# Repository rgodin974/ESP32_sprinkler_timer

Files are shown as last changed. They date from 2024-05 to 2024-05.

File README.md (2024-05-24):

# ESP32_sprinkler_timer

Sprinkler timer designed for ESP32.

Coded on PlateformIO and VS Code. Project based on RitonDuino : https://riton-duino.blogspot.com/2023/08/esp32-micro-irrigation-connectee-partie.html

Add few features :
- waterings every days
- waterings even days
- waterings odd days
- waterings custom days
- seasonal adjustment
- enable/disable watering(s)

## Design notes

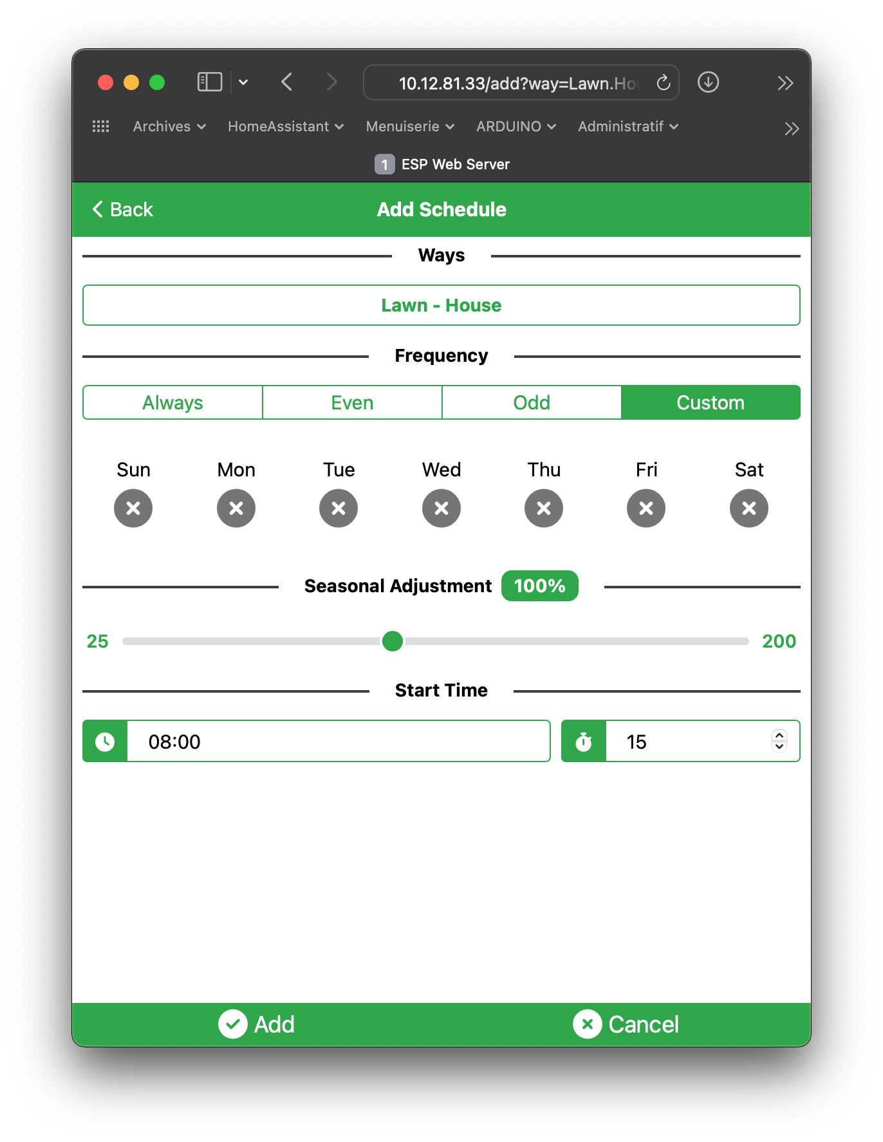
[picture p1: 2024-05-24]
sprinkler_add.png

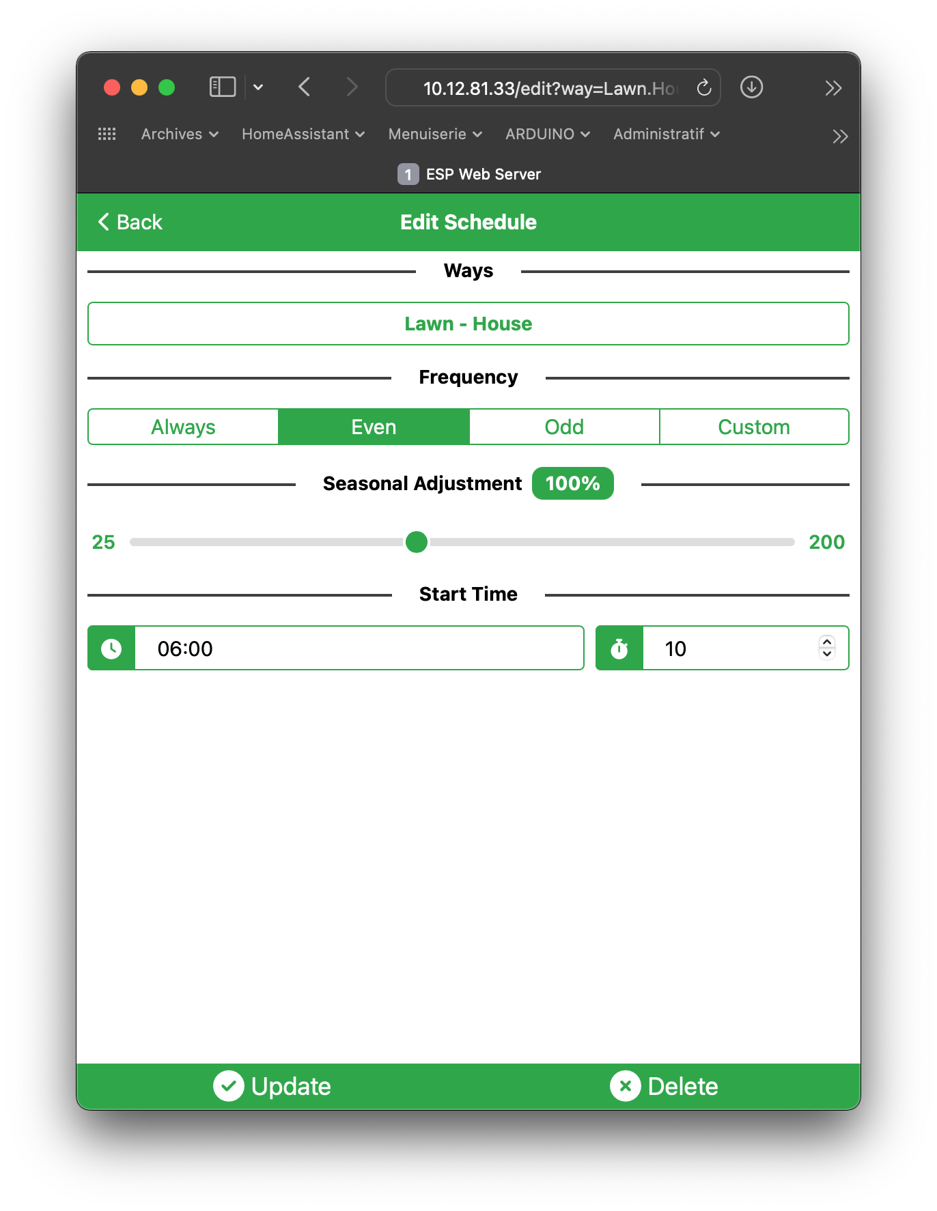
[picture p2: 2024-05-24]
sprinkler_edit.png

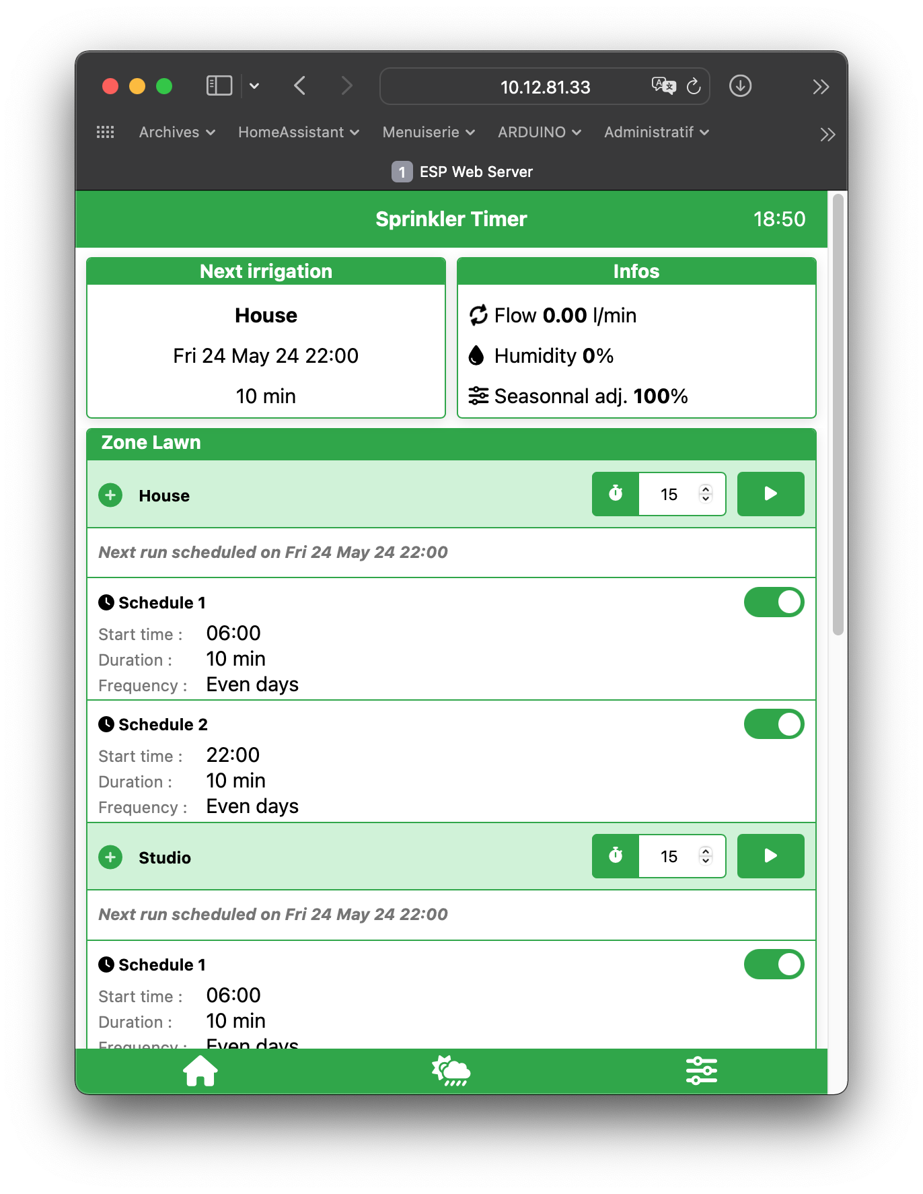
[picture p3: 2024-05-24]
sprinkler_home.png

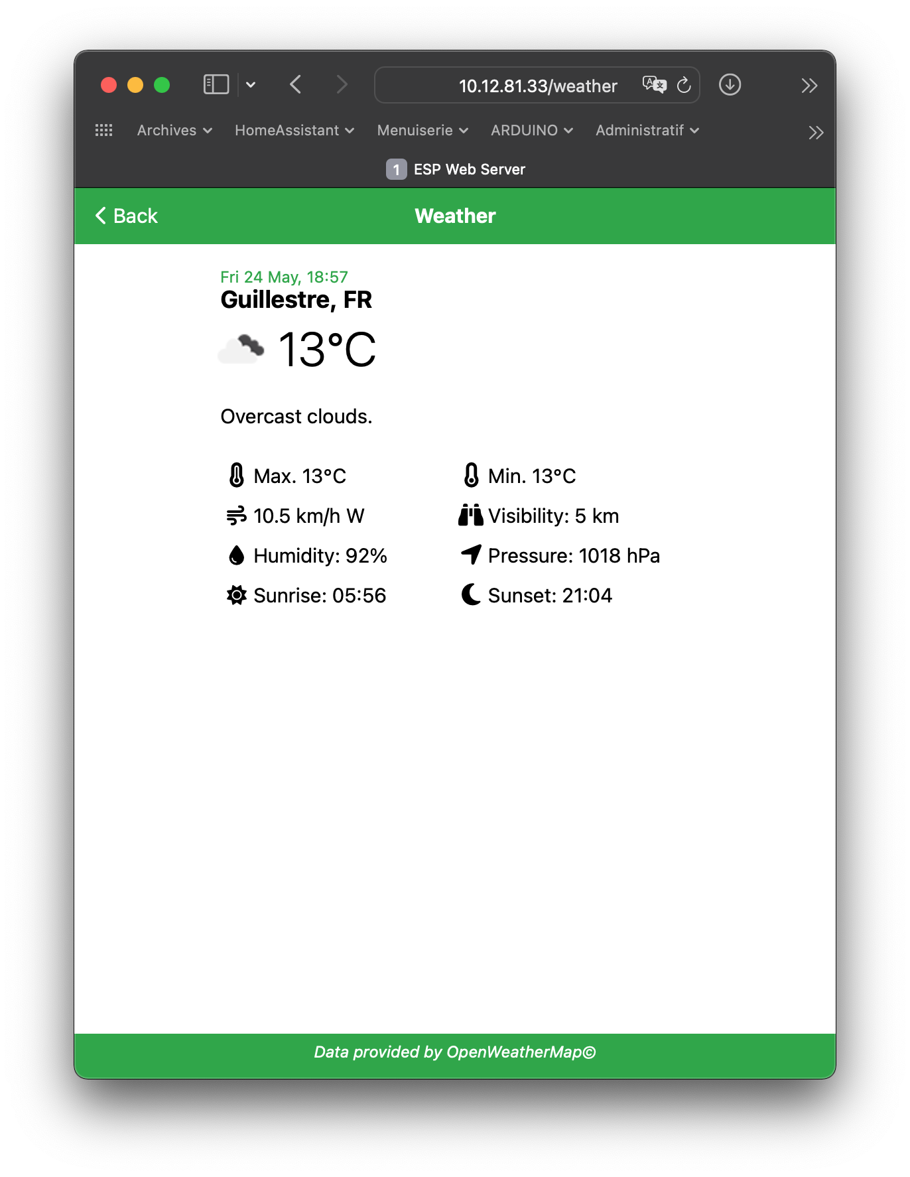
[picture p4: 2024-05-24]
sprinkler_weather.png

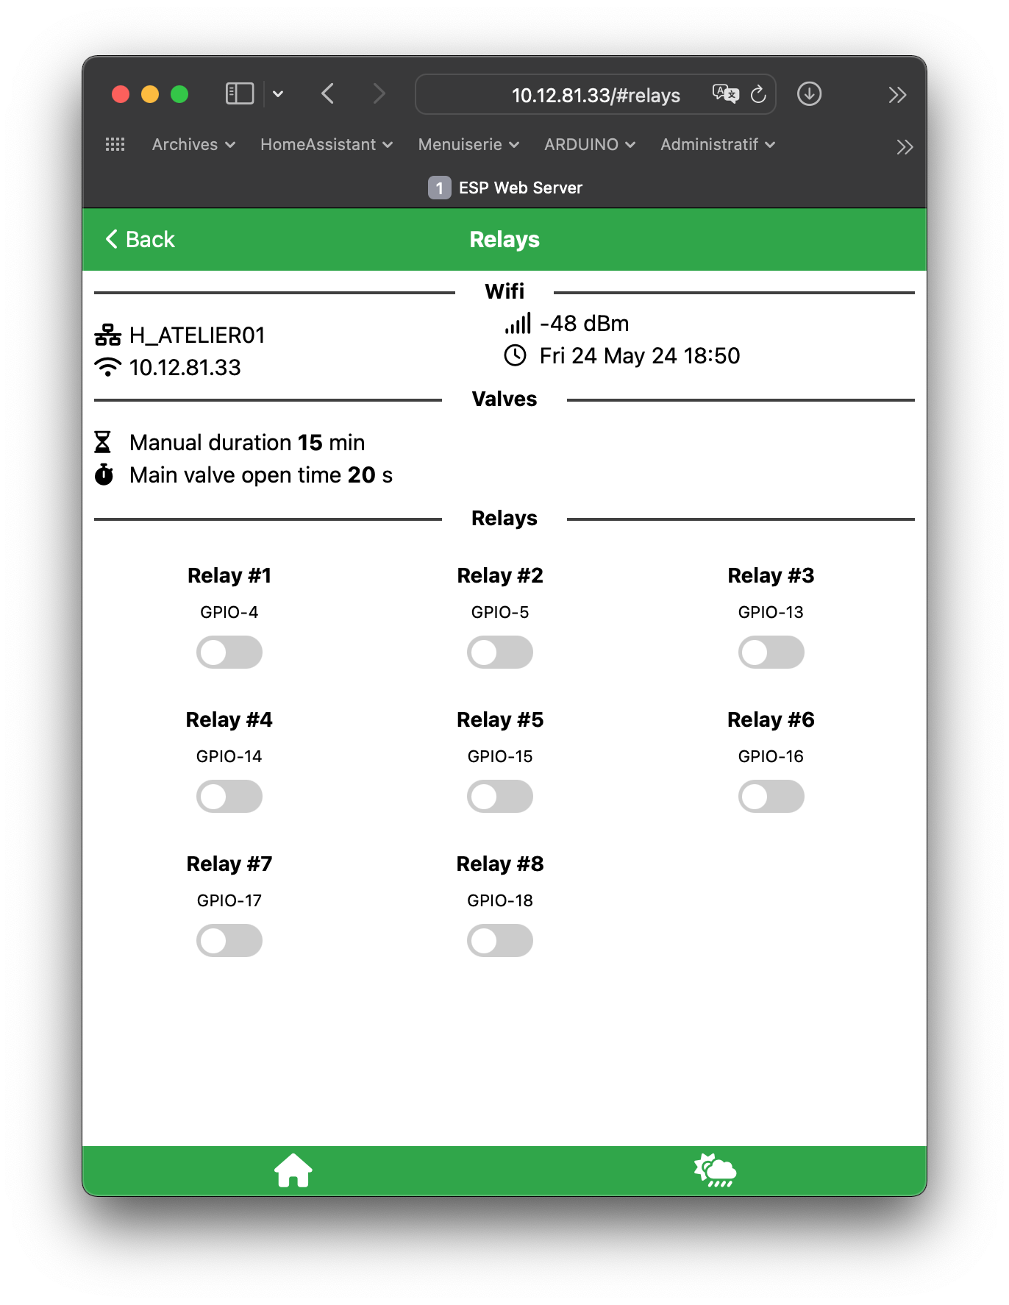
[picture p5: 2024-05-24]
sprinkler_infos.png

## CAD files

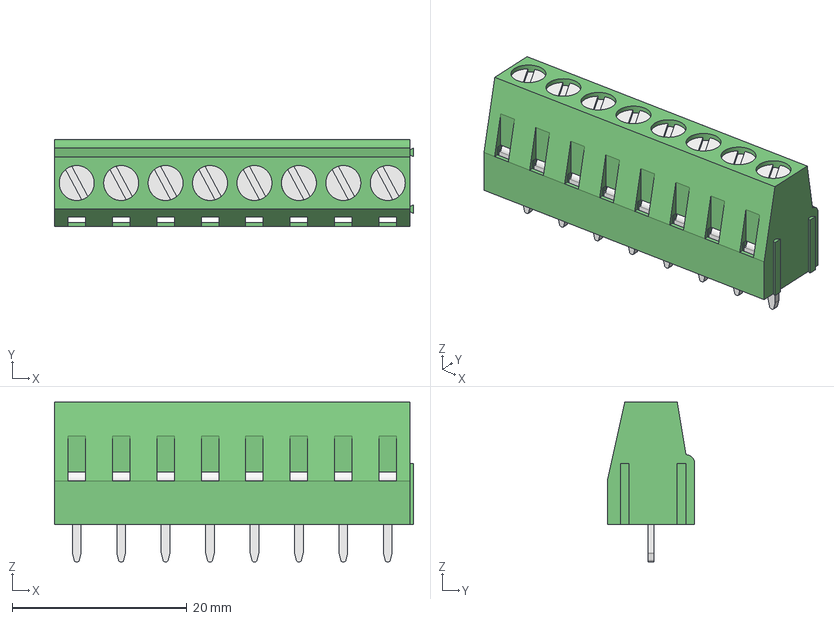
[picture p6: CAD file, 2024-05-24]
KiCAD/3D/8er Terminal Block.step
41.0 x 10.0 x 18.2 mm
Pin (1) (16)
Tornillo (1) (16)
Cubo interno (1) (16)
Pin (1) (1) (15)
Tornillo (1) (1) (15)
Cubo interno (1) (1) (15)
Pin (1) (14) (1)
Tornillo (1) (14) (1)
Cubo interno (1) (14) (1)
Pin (1) (1) (13) (1)
Tornillo (1) (1) (13) (1)
Cubo interno (1) (1) (13) (1)
Pin (1) (19) (1) (1) (1) (1) (1) (1)
Tornillo (1) (19) (1) (1) (1) (1) (1) (1)
Cubo interno (1) (19) (1) (1) (1) (1) (1) (1)
Pin (1) (1) (18) (1) (1) (1) (1) (1) (1)
Tornillo (1) (1) (18) (1) (1) (1) (1) (1) (1)
Cubo interno (1) (1) (18) (1) (1) (1) (1) (1) (1)
Pin (1) (11) (1) (1) (1) (1) (1) (1)
Tornillo (1) (11) (1) (1) (1) (1) (1) (1)
Cubo interno (1) (11) (1) (1) (1) (1) (1) (1)
Pin (1) (1) (10) (1) (1) (1) (1) (1) (1)
Tornillo (1) (1) (10) (1) (1) (1) (1) (1) (1)
Cubo interno (1) (1) (10) (1) (1) (1) (1) (1) (1)
Pin (1) (17) (1) (1) (1) (1) (1)
Tornillo (1) (17) (1) (1) (1) (1) (1)
Cubo interno (1) (17) (1) (1) (1) (1) (1)
Pin (1) (1) (16) (1) (1) (1) (1) (1)
Tornillo (1) (1) (16) (1) (1) (1) (1) (1)
Cubo interno (1) (1) (16) (1) (1) (1) (1) (1)
Pin (1) (18) (1) (1) (1) (1)
Tornillo (1) (18) (1) (1) (1) (1)
Cubo interno (1) (18) (1) (1) (1) (1)
Pin (1) (1) (17) (1) (1) (1) (1)
Tornillo (1) (1) (17) (1) (1) (1) (1)
Cubo interno (1) (1) (17) (1) (1) (1) (1)
Pin (1) (20) (1) (1) (1)
Tornillo (1) (20) (1) (1) (1)
Cubo interno (1) (20) (1) (1) (1)
Pin (1) (1) (19) (1) (1) (1)
Tornillo (1) (1) (19) (1) (1) (1)
Cubo interno (1) (1) (19) (1) (1) (1)
Pin (1) (13) (1) (1)
Tornillo (1) (13) (1) (1)
Cubo interno (1) (13) (1) (1)
Pin (1) (1) (12) (1) (1)
Tornillo (1) (1) (12) (1) (1)
Cubo interno (1) (1) (12) (1) (1)

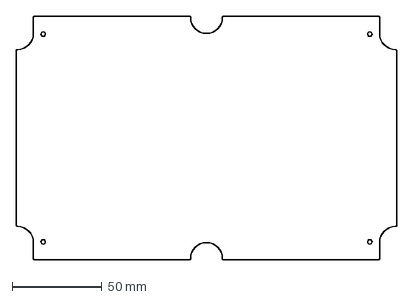
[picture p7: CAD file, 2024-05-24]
KiCAD/Board.dxf
211.3 x 135.3 mm

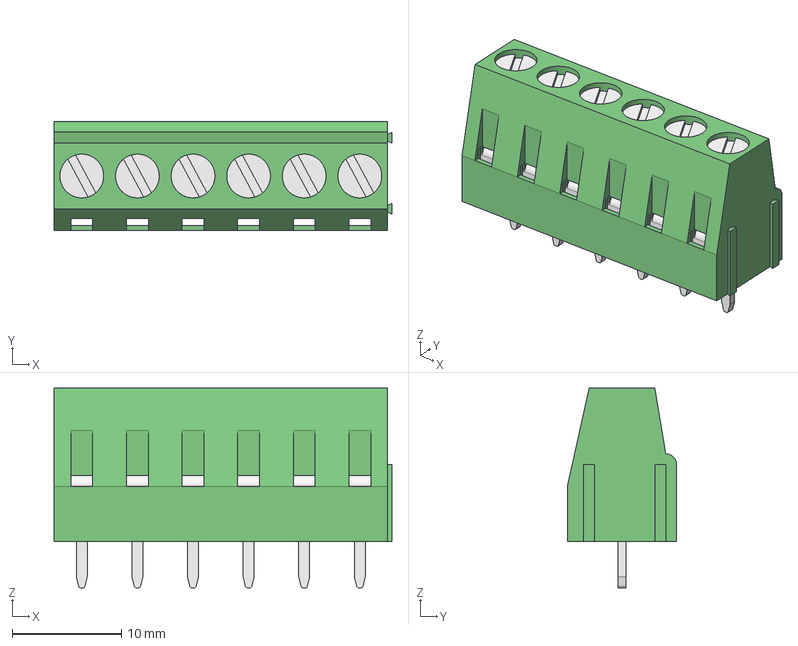
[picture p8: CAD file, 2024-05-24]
KiCAD/3D/6er Terminal Block.step
30.9 x 10.0 x 18.2 mm
Pin (1) (19) (1) (1) (1) (1)
Tornillo (1) (19) (1) (1) (1) (1)
Cubo interno (1) (19) (1) (1) (1) (1)
Pin (1) (1) (18) (1) (1) (1) (1)
Tornillo (1) (1) (18) (1) (1) (1) (1)
Cubo interno (1) (1) (18) (1) (1) (1) (1)
Pin (1) (11) (1) (1) (1) (1)
Tornillo (1) (11) (1) (1) (1) (1)
Cubo interno (1) (11) (1) (1) (1) (1)
Pin (1) (1) (10) (1) (1) (1) (1)
Tornillo (1) (1) (10) (1) (1) (1) (1)
Cubo interno (1) (1) (10) (1) (1) (1) (1)
Pin (1) (17) (1) (1) (1)
Tornillo (1) (17) (1) (1) (1)
Cubo interno (1) (17) (1) (1) (1)
Pin (1) (1) (16) (1) (1) (1)
Tornillo (1) (1) (16) (1) (1) (1)
Cubo interno (1) (1) (16) (1) (1) (1)
Pin (1) (18) (1) (1)
Tornillo (1) (18) (1) (1)
Cubo interno (1) (18) (1) (1)
Pin (1) (1) (17) (1) (1)
Tornillo (1) (1) (17) (1) (1)
Cubo interno (1) (1) (17) (1) (1)
Pin (1) (20) (1)
Tornillo (1) (20) (1)
Cubo interno (1) (20) (1)
Pin (1) (1) (19) (1)
Tornillo (1) (1) (19) (1)
Cubo interno (1) (1) (19) (1)
Pin (1) (13)
Tornillo (1) (13)
Cubo interno (1) (13)
Pin (1) (1) (12)
Tornillo (1) (1) (12)
Cubo interno (1) (1) (12)

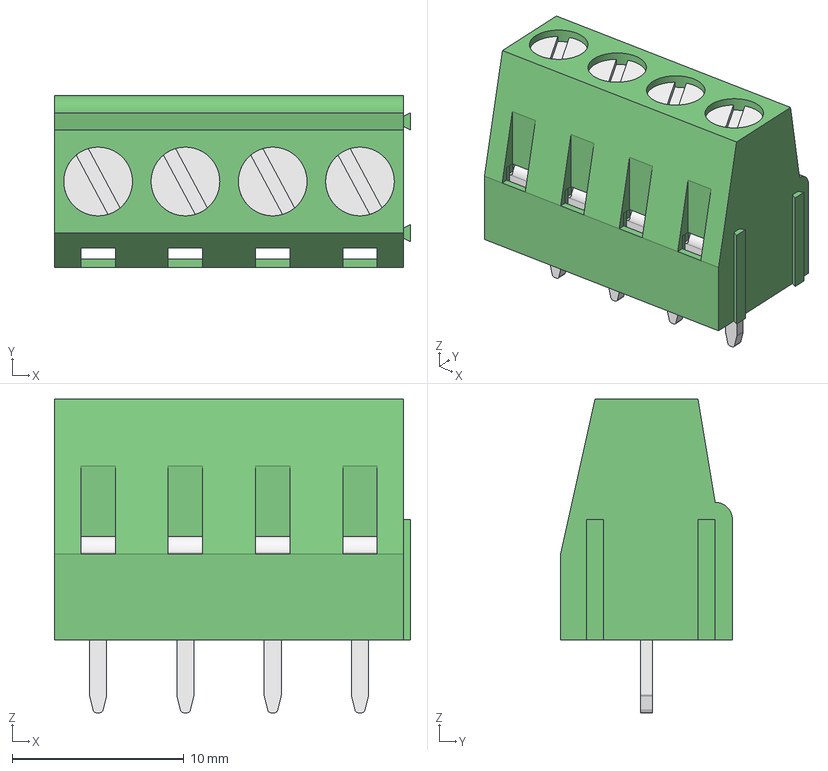
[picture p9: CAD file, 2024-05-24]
KiCAD/3D/4er Terminal Block.step
20.7 x 10.0 x 18.2 mm
Pin (1) (19) (1) (1)
Tornillo (1) (19) (1) (1)
Cubo interno (1) (19) (1) (1)
Pin (1) (1) (18) (1) (1)
Tornillo (1) (1) (18) (1) (1)
Cubo interno (1) (1) (18) (1) (1)
Pin (1) (11) (1) (1)
Tornillo (1) (11) (1) (1)
Cubo interno (1) (11) (1) (1)
Pin (1) (1) (10) (1) (1)
Tornillo (1) (1) (10) (1) (1)
Cubo interno (1) (1) (10) (1) (1)
Pin (1) (17) (1)
Tornillo (1) (17) (1)
Cubo interno (1) (17) (1)
Pin (1) (1) (16) (1)
Tornillo (1) (1) (16) (1)
Cubo interno (1) (1) (16) (1)
Pin (1) (18)
Tornillo (1) (18)
Cubo interno (1) (18)
Pin (1) (1) (17)
Tornillo (1) (1) (17)
Cubo interno (1) (1) (17)

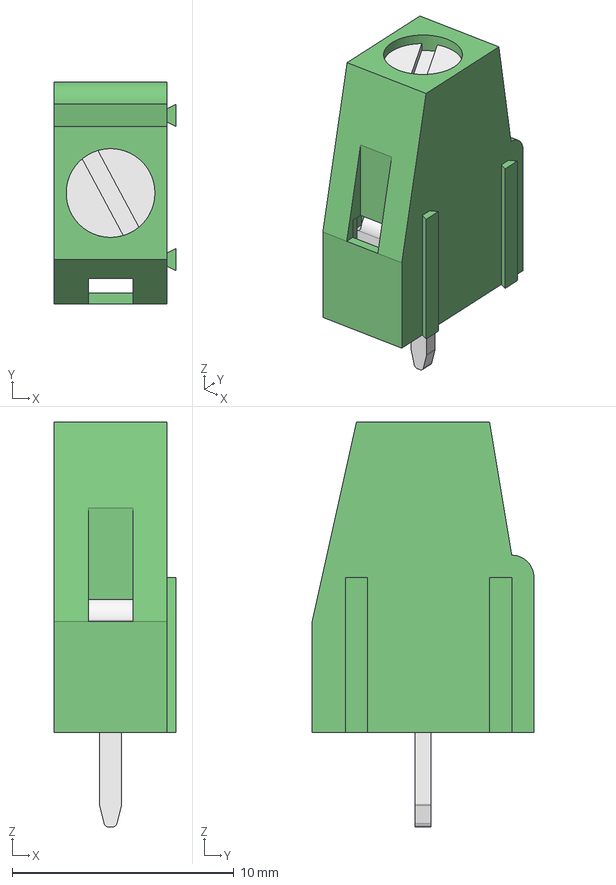
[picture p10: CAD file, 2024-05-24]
KiCAD/3D/1er Terminal Block.step
5.48 x 10.0 x 18.2 mm
Pin (1)
Tornillo (1)
Cubo interno (1)
Pin (1) (1)
Tornillo (1) (1)
Cubo interno (1) (1)

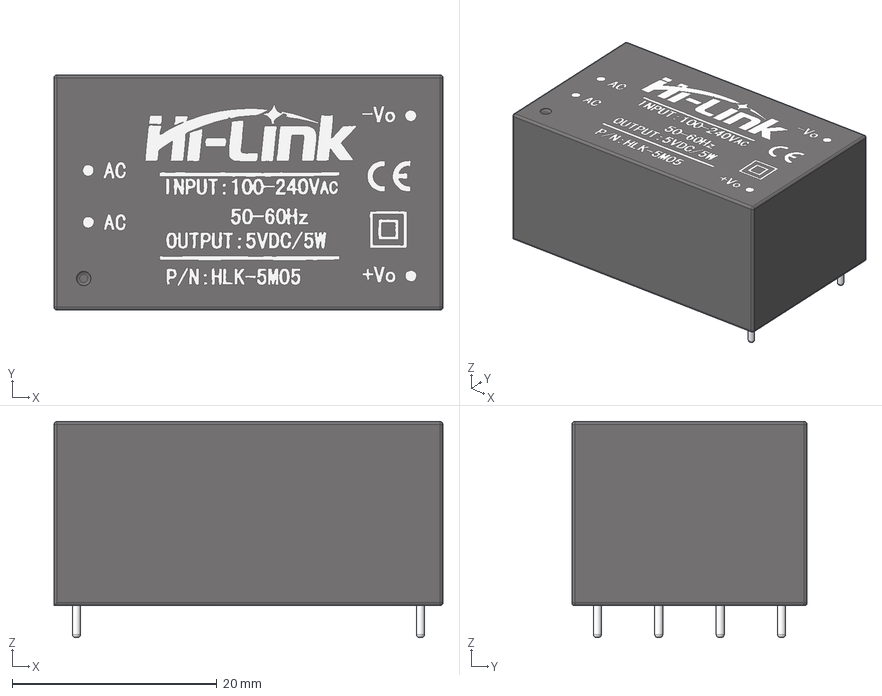
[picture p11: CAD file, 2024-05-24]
KiCAD/3D/HLK-5M05.step
38.0 x 23.0 x 21.1 mm

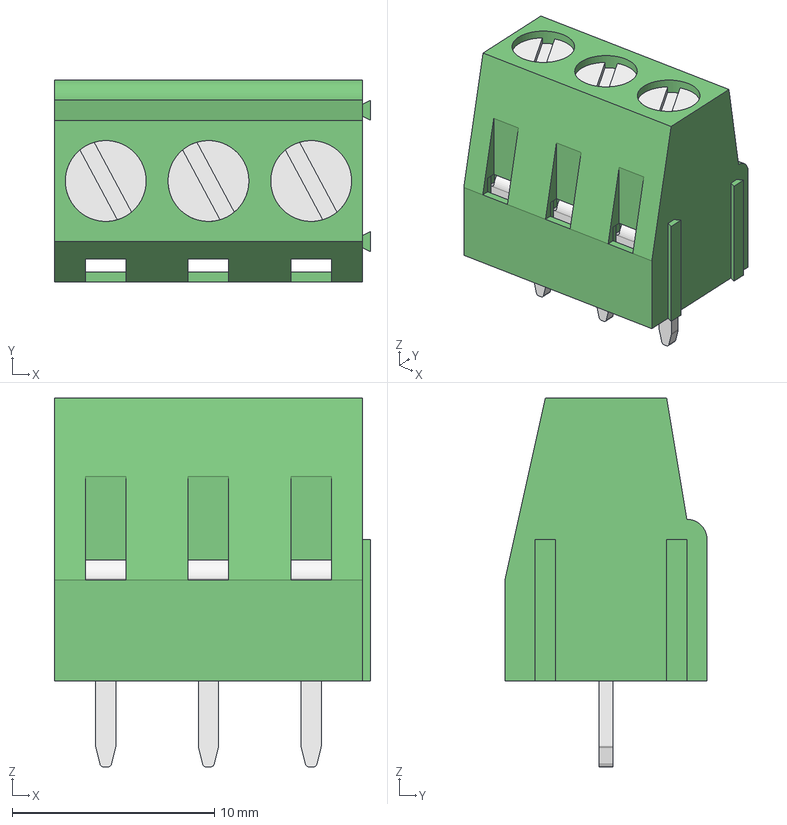
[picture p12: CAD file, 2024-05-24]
KiCAD/3D/3er Terminal Block.step
15.6 x 10.0 x 18.2 mm
Pin (1) (19) (1)
Tornillo (1) (19) (1)
Cubo interno (1) (19) (1)
Pin (1) (1) (18) (1)
Tornillo (1) (1) (18) (1)
Cubo interno (1) (1) (18) (1)
Pin (1) (11) (1)
Tornillo (1) (11) (1)
Cubo interno (1) (11) (1)
Pin (1) (1) (10) (1)
Tornillo (1) (1) (10) (1)
Cubo interno (1) (1) (10) (1)
Pin (1) (17)
Tornillo (1) (17)
Cubo interno (1) (17)
Pin (1) (1) (16)
Tornillo (1) (1) (16)
Cubo interno (1) (1) (16)

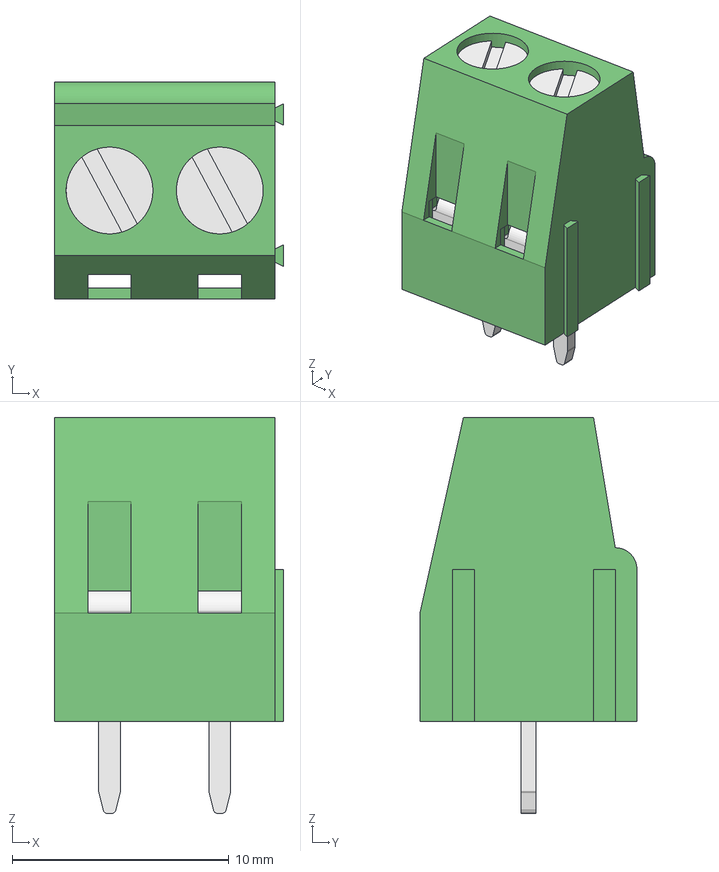
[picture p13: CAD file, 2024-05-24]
KiCAD/3D/2er Terminal Block.step
10.6 x 10.0 x 18.2 mm
Pin (1) (19)
Tornillo (1) (19)
Cubo interno (1) (19)
Pin (1) (1) (18)
Tornillo (1) (1) (18)
Cubo interno (1) (1) (18)
Pin (1) (11)
Tornillo (1) (11)
Cubo interno (1) (11)
Pin (1) (1) (10)
Tornillo (1) (1) (10)
Cubo interno (1) (1) (10)

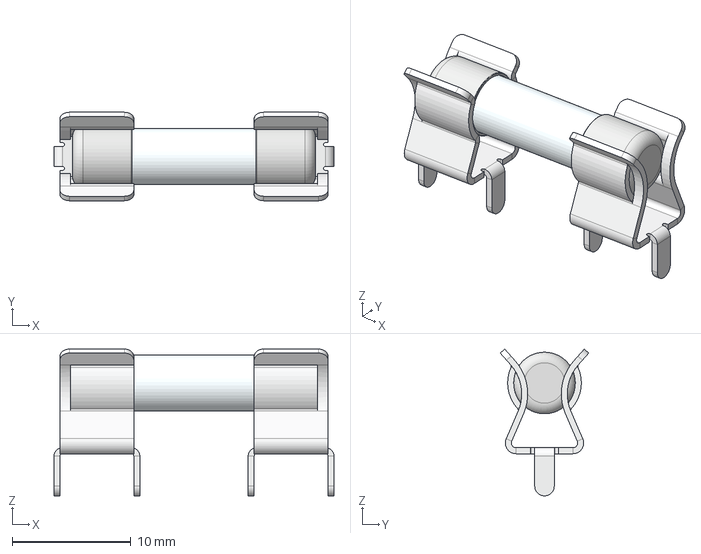
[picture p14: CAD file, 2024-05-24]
KiCAD/3D/FC-201-22_5TT.stp
23.6 x 7.47 x 12.4 mm

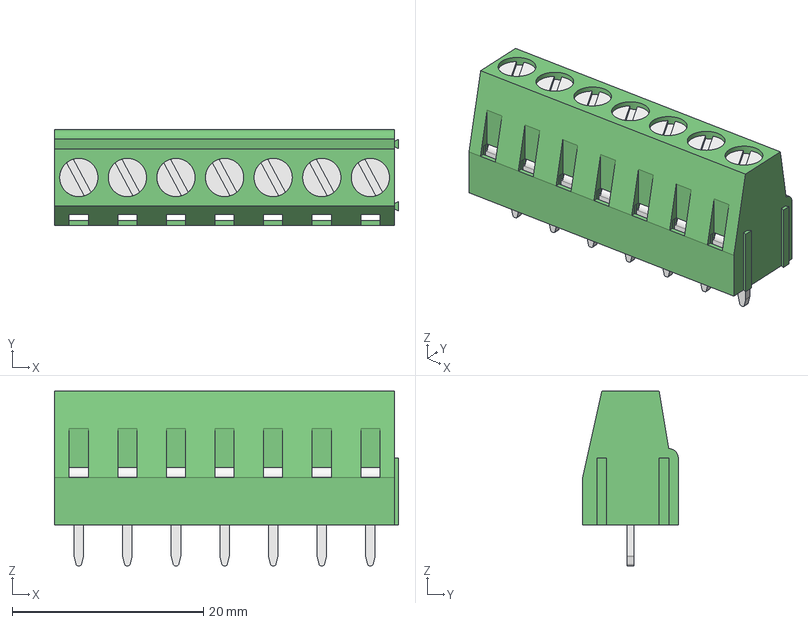
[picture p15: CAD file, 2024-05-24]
KiCAD/3D/7er Terminal Block.step
36.0 x 10.0 x 18.2 mm
Pin (1) (14)
Tornillo (1) (14)
Cubo interno (1) (14)
Pin (1) (1) (13)
Tornillo (1) (1) (13)
Cubo interno (1) (1) (13)
Pin (1) (19) (1) (1) (1) (1) (1)
Tornillo (1) (19) (1) (1) (1) (1) (1)
Cubo interno (1) (19) (1) (1) (1) (1) (1)
Pin (1) (1) (18) (1) (1) (1) (1) (1)
Tornillo (1) (1) (18) (1) (1) (1) (1) (1)
Cubo interno (1) (1) (18) (1) (1) (1) (1) (1)
Pin (1) (11) (1) (1) (1) (1) (1)
Tornillo (1) (11) (1) (1) (1) (1) (1)
Cubo interno (1) (11) (1) (1) (1) (1) (1)
Pin (1) (1) (10) (1) (1) (1) (1) (1)
Tornillo (1) (1) (10) (1) (1) (1) (1) (1)
Cubo interno (1) (1) (10) (1) (1) (1) (1) (1)
Pin (1) (17) (1) (1) (1) (1)
Tornillo (1) (17) (1) (1) (1) (1)
Cubo interno (1) (17) (1) (1) (1) (1)
Pin (1) (1) (16) (1) (1) (1) (1)
Tornillo (1) (1) (16) (1) (1) (1) (1)
Cubo interno (1) (1) (16) (1) (1) (1) (1)
Pin (1) (18) (1) (1) (1)
Tornillo (1) (18) (1) (1) (1)
Cubo interno (1) (18) (1) (1) (1)
Pin (1) (1) (17) (1) (1) (1)
Tornillo (1) (1) (17) (1) (1) (1)
Cubo interno (1) (1) (17) (1) (1) (1)
Pin (1) (20) (1) (1)
Tornillo (1) (20) (1) (1)
Cubo interno (1) (20) (1) (1)
Pin (1) (1) (19) (1) (1)
Tornillo (1) (1) (19) (1) (1)
Cubo interno (1) (1) (19) (1) (1)
Pin (1) (13) (1)
Tornillo (1) (13) (1)
Cubo interno (1) (13) (1)
Pin (1) (1) (12) (1)
Tornillo (1) (1) (12) (1)
Cubo interno (1) (1) (12) (1)

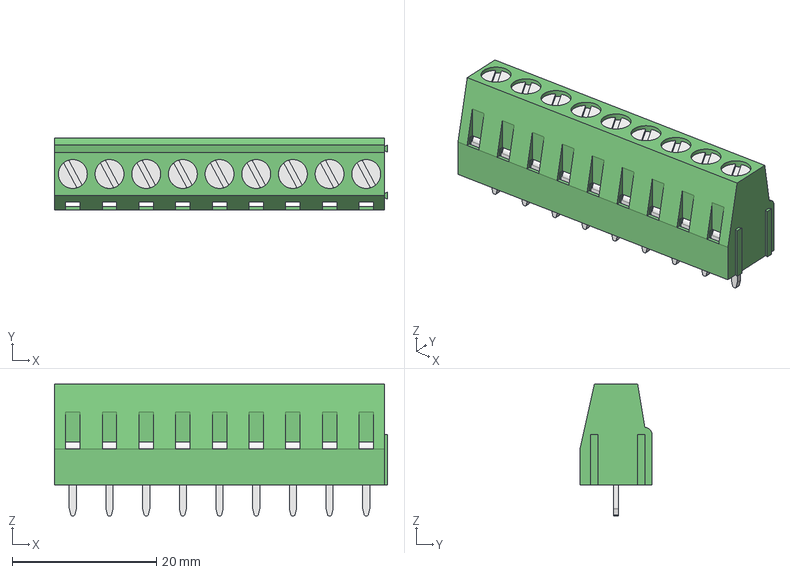
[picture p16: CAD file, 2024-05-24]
KiCAD/3D/9er Terminal Block.step
46.1 x 10.0 x 18.2 mm
Pin (1) (16) (1)
Tornillo (1) (16) (1)
Cubo interno (1) (16) (1)
Pin (1) (1) (15) (1)
Tornillo (1) (1) (15) (1)
Cubo interno (1) (1) (15) (1)
Pin (1) (14) (1) (1)
Tornillo (1) (14) (1) (1)
Cubo interno (1) (14) (1) (1)
Pin (1) (1) (13) (1) (1)
Tornillo (1) (1) (13) (1) (1)
Cubo interno (1) (1) (13) (1) (1)
Pin (1) (19) (1) (1) (1) (1) (1) (1) (1)
Tornillo (1) (19) (1) (1) (1) (1) (1) (1) (1)
Cubo interno (1) (19) (1) (1) (1) (1) (1) (1) (1)
Pin (1) (1) (18) (1) (1) (1) (1) (1) (1) (1)
Tornillo (1) (1) (18) (1) (1) (1) (1) (1) (1) (1)
Cubo interno (1) (1) (18) (1) (1) (1) (1) (1) (1) (1)
Pin (1) (11) (1) (1) (1) (1) (1) (1) (1)
Tornillo (1) (11) (1) (1) (1) (1) (1) (1) (1)
Cubo interno (1) (11) (1) (1) (1) (1) (1) (1) (1)
Pin (1) (1) (10) (1) (1) (1) (1) (1) (1) (1)
Tornillo (1) (1) (10) (1) (1) (1) (1) (1) (1) (1)
Cubo interno (1) (1) (10) (1) (1) (1) (1) (1) (1) (1)
Pin (1) (17) (1) (1) (1) (1) (1) (1)
Tornillo (1) (17) (1) (1) (1) (1) (1) (1)
Cubo interno (1) (17) (1) (1) (1) (1) (1) (1)
Pin (1) (1) (16) (1) (1) (1) (1) (1) (1)
Tornillo (1) (1) (16) (1) (1) (1) (1) (1) (1)
Cubo interno (1) (1) (16) (1) (1) (1) (1) (1) (1)
Pin (1) (18) (1) (1) (1) (1) (1)
Tornillo (1) (18) (1) (1) (1) (1) (1)
Cubo interno (1) (18) (1) (1) (1) (1) (1)
Pin (1) (1) (17) (1) (1) (1) (1) (1)
Tornillo (1) (1) (17) (1) (1) (1) (1) (1)
Cubo interno (1) (1) (17) (1) (1) (1) (1) (1)
Pin (1) (20) (1) (1) (1) (1)
Tornillo (1) (20) (1) (1) (1) (1)
Cubo interno (1) (20) (1) (1) (1) (1)
Pin (1) (1) (19) (1) (1) (1) (1)
Tornillo (1) (1) (19) (1) (1) (1) (1)
Cubo interno (1) (1) (19) (1) (1) (1) (1)
Pin (1) (13) (1) (1) (1)
Tornillo (1) (13) (1) (1) (1)
Cubo interno (1) (13) (1) (1) (1)
Pin (1) (1) (12) (1) (1) (1)
Tornillo (1) (1) (12) (1) (1) (1)
Cubo interno (1) (1) (12) (1) (1) (1)
Pin (1) (15)
Tornillo (1) (15)
Cubo interno (1) (15)
Pin (1) (1) (14)
Tornillo (1) (1) (14)
Cubo interno (1) (1) (14)

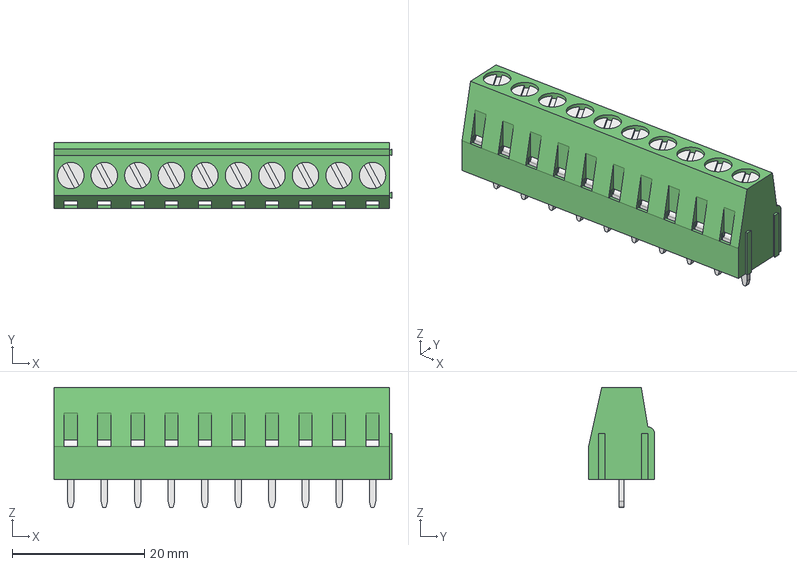
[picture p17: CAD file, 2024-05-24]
KiCAD/3D/10er Terminal Block.step
51.2 x 10.0 x 18.2 mm
Pin (1) (12)
Tornillo (1) (12)
Cubo interno (1) (12)
Pin (1) (1) (11)
Tornillo (1) (1) (11)
Cubo interno (1) (1) (11)
Pin (1) (16) (1) (1)
Tornillo (1) (16) (1) (1)
Cubo interno (1) (16) (1) (1)
Pin (1) (1) (15) (1) (1)
Tornillo (1) (1) (15) (1) (1)
Cubo interno (1) (1) (15) (1) (1)
Pin (1) (14) (1) (1) (1)
Tornillo (1) (14) (1) (1) (1)
Cubo interno (1) (14) (1) (1) (1)
Pin (1) (1) (13) (1) (1) (1)
Tornillo (1) (1) (13) (1) (1) (1)
Cubo interno (1) (1) (13) (1) (1) (1)
Pin (1) (19) (1) (1) (1) (1) (1) (1) (1) (1)
Tornillo (1) (19) (1) (1) (1) (1) (1) (1) (1) (1)
Cubo interno (1) (19) (1) (1) (1) (1) (1) (1) (1) (1)
Pin (1) (1) (18) (1) (1) (1) (1) (1) (1) (1) (1)
Tornillo (1) (1) (18) (1) (1) (1) (1) (1) (1) (1) (1)
Cubo interno (1) (1) (18) (1) (1) (1) (1) (1) (1) (1) (1)
Pin (1) (11) (1) (1) (1) (1) (1) (1) (1) (1)
Tornillo (1) (11) (1) (1) (1) (1) (1) (1) (1) (1)
Cubo interno (1) (11) (1) (1) (1) (1) (1) (1) (1) (1)
Pin (1) (1) (10) (1) (1) (1) (1) (1) (1) (1) (1)
Tornillo (1) (1) (10) (1) (1) (1) (1) (1) (1) (1) (1)
Cubo interno (1) (1) (10) (1) (1) (1) (1) (1) (1) (1) (1)
Pin (1) (17) (1) (1) (1) (1) (1) (1) (1)
Tornillo (1) (17) (1) (1) (1) (1) (1) (1) (1)
Cubo interno (1) (17) (1) (1) (1) (1) (1) (1) (1)
Pin (1) (1) (16) (1) (1) (1) (1) (1) (1) (1)
Tornillo (1) (1) (16) (1) (1) (1) (1) (1) (1) (1)
Cubo interno (1) (1) (16) (1) (1) (1) (1) (1) (1) (1)
Pin (1) (18) (1) (1) (1) (1) (1) (1)
Tornillo (1) (18) (1) (1) (1) (1) (1) (1)
Cubo interno (1) (18) (1) (1) (1) (1) (1) (1)
Pin (1) (1) (17) (1) (1) (1) (1) (1) (1)
Tornillo (1) (1) (17) (1) (1) (1) (1) (1) (1)
Cubo interno (1) (1) (17) (1) (1) (1) (1) (1) (1)
Pin (1) (20) (1) (1) (1) (1) (1)
Tornillo (1) (20) (1) (1) (1) (1) (1)
Cubo interno (1) (20) (1) (1) (1) (1) (1)
Pin (1) (1) (19) (1) (1) (1) (1) (1)
Tornillo (1) (1) (19) (1) (1) (1) (1) (1)
Cubo interno (1) (1) (19) (1) (1) (1) (1) (1)
Pin (1) (13) (1) (1) (1) (1)
Tornillo (1) (13) (1) (1) (1) (1)
Cubo interno (1) (13) (1) (1) (1) (1)
Pin (1) (1) (12) (1) (1) (1) (1)
Tornillo (1) (1) (12) (1) (1) (1) (1)
Cubo interno (1) (1) (12) (1) (1) (1) (1)
Pin (1) (15) (1)
Tornillo (1) (15) (1)
Cubo interno (1) (15) (1)
Pin (1) (1) (14) (1)
Tornillo (1) (1) (14) (1)
Cubo interno (1) (1) (14) (1)

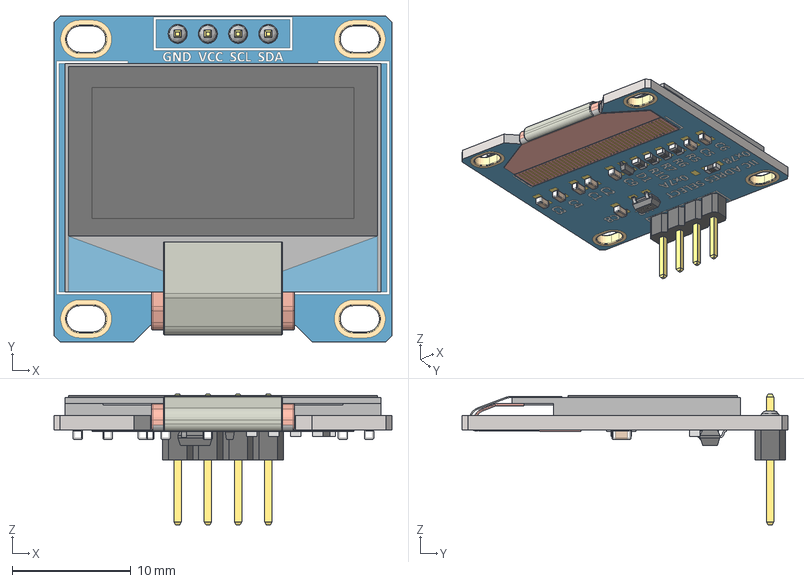
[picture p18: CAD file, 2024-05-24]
KiCAD/3D/OLED_0.96_I2C.step
28.4 x 27.4 x 11.0 mm
662k - XC6206P182MR-G
R SMD 472 x 4
R SMD 914
C SMD 0603 x 8
SOD323F_DIO

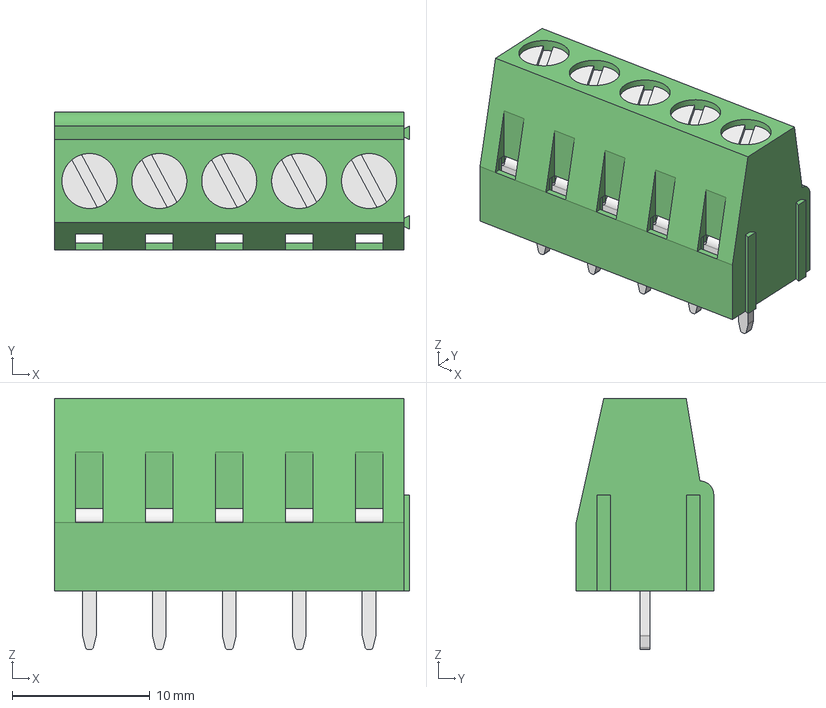
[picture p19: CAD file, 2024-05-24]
KiCAD/3D/5er Terminal Block.step
25.8 x 10.0 x 18.2 mm
Pin (1) (19) (1) (1) (1)
Tornillo (1) (19) (1) (1) (1)
Cubo interno (1) (19) (1) (1) (1)
Pin (1) (1) (18) (1) (1) (1)
Tornillo (1) (1) (18) (1) (1) (1)
Cubo interno (1) (1) (18) (1) (1) (1)
Pin (1) (11) (1) (1) (1)
Tornillo (1) (11) (1) (1) (1)
Cubo interno (1) (11) (1) (1) (1)
Pin (1) (1) (10) (1) (1) (1)
Tornillo (1) (1) (10) (1) (1) (1)
Cubo interno (1) (1) (10) (1) (1) (1)
Pin (1) (17) (1) (1)
Tornillo (1) (17) (1) (1)
Cubo interno (1) (17) (1) (1)
Pin (1) (1) (16) (1) (1)
Tornillo (1) (1) (16) (1) (1)
Cubo interno (1) (1) (16) (1) (1)
Pin (1) (18) (1)
Tornillo (1) (18) (1)
Cubo interno (1) (18) (1)
Pin (1) (1) (17) (1)
Tornillo (1) (1) (17) (1)
Cubo interno (1) (1) (17) (1)
Pin (1) (20)
Tornillo (1) (20)
Cubo interno (1) (20)
Pin (1) (1) (19)
Tornillo (1) (1) (19)
Cubo interno (1) (1) (19)

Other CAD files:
KiCAD/3D/G2RL_1.step
KiCAD/3D/HLK-10M024.step

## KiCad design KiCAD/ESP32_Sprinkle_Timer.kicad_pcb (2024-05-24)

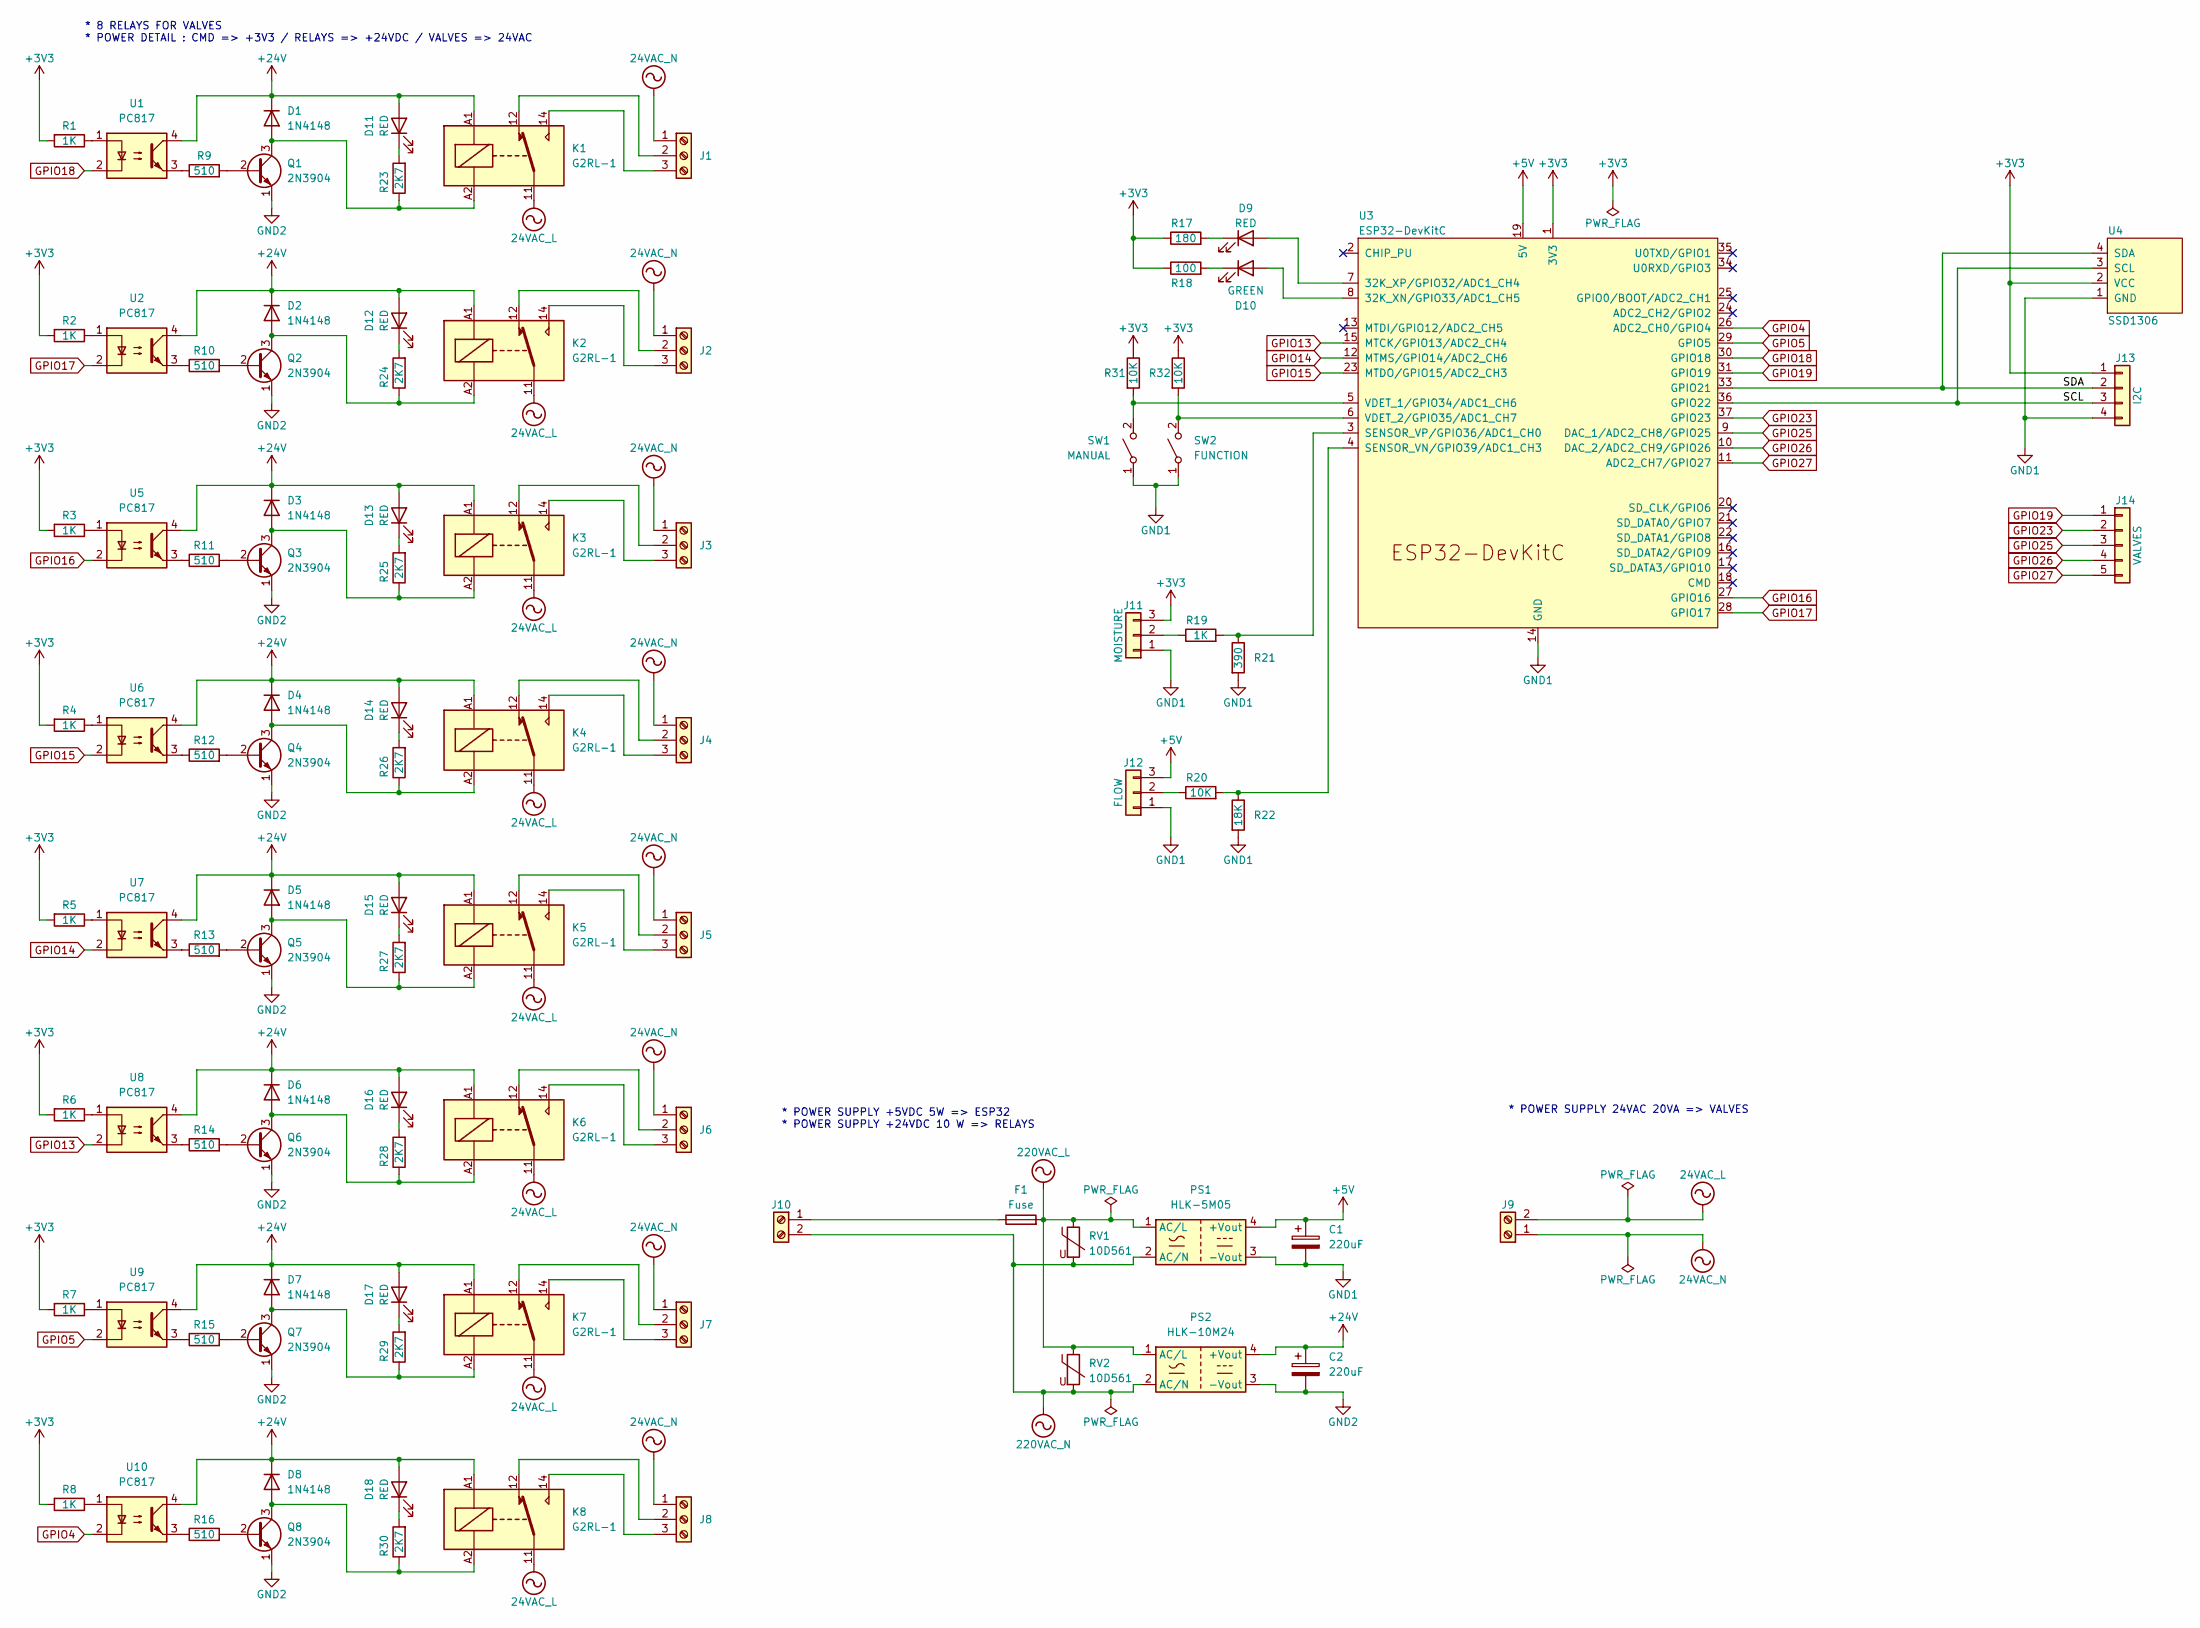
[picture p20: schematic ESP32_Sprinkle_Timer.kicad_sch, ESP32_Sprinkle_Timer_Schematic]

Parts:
C1: 220uF; CP_Radial_D8.0mm_P3.50mm
C2: 220uF; CP_Radial_D10.0mm_P5.00mm
D1, D2, D3, D4, D5, D6, D7, D8: 1N4148; D_DO-35_SOD27_P7.62mm_Horizontal
D9, D11, D12, D13, D14, D15, D16, D17, D18: RED; LED_D3.0mm
D10: GREEN; LED_D3.0mm
F1: Fuse; Fuseholder_Cylinder-5x20mm_Schurter_0031_8201_Horizontal_Op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
J1, J2, J3, J4, J5, J6, J7, J8: Screw_Terminal_01x03; TerminalBlock_bornier-3_P5.08mm
J9, J10: Screw_Terminal_01x02; TerminalBlock_bornier-2_P5.08mm
J11: MOISTURE; PinHeader_1x03_P2.54mm_Horizontal
J12: FLOW; PinHeader_1x03_P2.54mm_Horizontal
J13: I2C; PinHeader_1x04_P2.54mm_Vertical
J14: VALVES; PinHeader_1x05_P2.54mm_Vertical
K1, K2, K3, K4, K5, K6, K7, K8: G2RL-1; Relay_SPDT_Omron_G2RL-1
PS1: HLK-5M05; Converter_ACDC_HiLink_HLK-5Mxx
PS2: HLK-10M24; Converter_ACDC_HiLink_HLK-10Mxx
Q1, Q2, Q3, Q4, Q5, Q6, Q7, Q8: 2N3904; TO-92_Inline_Wide
R1, R2, R3, R4, R5, R6, R7, R8, R19: 1K; R_Axial_DIN0207_L6.3mm_D2.5mm_P7.62mm_Horizontal
R9, R10, R11, R12, R13, R14, R15, R16: 510; R_Axial_DIN0207_L6.3mm_D2.5mm_P7.62mm_Horizontal
R17: 180; R_Axial_DIN0207_L6.3mm_D2.5mm_P7.62mm_Horizontal
R18: 100; R_Axial_DIN0207_L6.3mm_D2.5mm_P7.62mm_Horizontal
R20, R31, R32: 10K; R_Axial_DIN0207_L6.3mm_D2.5mm_P7.62mm_Horizontal
R21: 390; R_Axial_DIN0207_L6.3mm_D2.5mm_P7.62mm_Horizontal
R22: 18K; R_Axial_DIN0207_L6.3mm_D2.5mm_P7.62mm_Horizontal
R23, R24, R25, R26, R27, R28, R29, R30: 2K7; R_Axial_DIN0207_L6.3mm_D2.5mm_P7.62mm_Horizontal
RV1, RV2: 10D561; RV_Disc_D12mm_W7.5mm_P7.5mm
SW1: MANUAL; SW_PUSH-12mm
SW2: FUNCTION; SW_PUSH-12mm
U1, U2, U5, U6, U7, U8, U9, U10: PC817; DIP-4_W7.62mm
U3: ESP32-DevKitC
U4: SSD1306; SSD1306_0.96_Oled

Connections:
24VAC_L: J9.2, K1.11, K2.11, K3.11, K4.11, K5.11, K6.11, K7.11, K8.11
24VAC_N: J1.1, J2.1, J3.1, J4.1, J5.1, J6.1, J7.1, J8.1, J9.1
220VAC_L: F1.2, PS1.1 (AC/L), PS2.1 (AC/L), RV1.1, RV2.1
220VAC_N: J10.2, PS1.2 (AC/N), PS2.2 (AC/N), RV1.2, RV2.2
+3V3: J11.3, J13.1, R1.2, R2.2, R3.2, R4.2, R5.2, R6.2, R7.2, R8.2, R17.1, R18.1, R31.1, R32.1, U3.1 (3V3), U4.2 (VCC)
+5V: C1.1, J12.3, PS1.4 (+Vout), U3.19 (5V)
+24V: C2.1, D1.1 (K), D2.1 (K), D3.1 (K), D4.1 (K), D5.1 (K), D6.1 (K), D7.1 (K), D8.1 (K), D11.2 (A), D12.2 (A), D13.2 (A), D14.2 (A), D15.2 (A), D16.2 (A), D17.2 (A), D18.2 (A), K1.A1, K2.A1, K3.A1, K4.A1, K5.A1, K6.A1, K7.A1, K8.A1, PS2.4 (+Vout), U1.4, U2.4, U5.4, U6.4, U7.4, U8.4, U9.4, U10.4
/SCL: J13.3, U3.36 (GPIO22), U4.3 (SCL)
/SDA: J13.2, U3.33 (GPIO21), U4.4 (SDA)
GND1: C1.2, J11.1, J12.1, J13.4, PS1.3 (-Vout), R21.2, R22.2, SW1.1 (A), SW2.1 (A), U3.14 (GND), U3.32 (GND), U3.38 (GND), U4.1 (GND)
GND2: C2.2, PS2.3 (-Vout), Q1.1 (E), Q2.1 (E), Q3.1 (E), Q4.1 (E), Q5.1 (E), Q6.1 (E), Q7.1 (E), Q8.1 (E)
GPIO4: U3.26 (ADC2_CH0/GPIO4), U10.2
GPIO5: U3.29 (GPIO5), U9.2
GPIO13: U3.15 (MTCK/GPIO13/ADC2_CH4), U8.2
GPIO14: U3.12 (MTMS/GPIO14/ADC2_CH6), U7.2
GPIO15: U3.23 (MTDO/GPIO15/ADC2_CH3), U6.2
GPIO16: U3.27 (GPIO16), U5.2
GPIO17: U2.2, U3.28 (GPIO17)
GPIO18: U1.2, U3.30 (GPIO18)
GPIO19: J14.1, U3.31 (GPIO19)
GPIO23: J14.2, U3.37 (GPIO23)
GPIO25: J14.3, U3.9 (DAC_1/ADC2_CH8/GPIO25)
GPIO26: J14.4, U3.10 (DAC_2/ADC2_CH9/GPIO26)
GPIO27: J14.5, U3.11 (ADC2_CH7/GPIO27)
unnamed: D1.2 (A), K1.A2, Q1.3 (C), R23.1
unnamed: D2.2 (A), K2.A2, Q2.3 (C), R24.1
unnamed: D3.2 (A), K3.A2, Q3.3 (C), R25.1
unnamed: D4.2 (A), K4.A2, Q4.3 (C), R26.1
unnamed: D5.2 (A), K5.A2, Q5.3 (C), R27.1
unnamed: D6.2 (A), K6.A2, Q6.3 (C), R28.1
unnamed: D7.2 (A), K7.A2, Q7.3 (C), R29.1
unnamed: D8.2 (A), K8.A2, Q8.3 (C), R30.1
unnamed: D9.2 (A), U3.7 (32K_XP/GPIO32/ADC1_CH4)
unnamed: D9.1 (K), R17.2
unnamed: D10.2 (A), U3.8 (32K_XN/GPIO33/ADC1_CH5)
unnamed: D10.1 (K), R18.2
unnamed: D11.1 (K), R23.2
unnamed: D12.1 (K), R24.2
unnamed: D13.1 (K), R25.2
unnamed: D14.1 (K), R26.2
unnamed: D15.1 (K), R27.2
unnamed: D16.1 (K), R28.2
unnamed: D17.1 (K), R29.2
unnamed: D18.1 (K), R30.2
unnamed: J1.2, K1.12
unnamed: J1.3, K1.14
unnamed: J2.2, K2.12
unnamed: J2.3, K2.14
unnamed: J3.2, K3.12
unnamed: J3.3, K3.14
unnamed: J4.2, K4.12
unnamed: J4.3, K4.14
unnamed: J5.2, K5.12
unnamed: J5.3, K5.14
unnamed: J6.2, K6.12
unnamed: J6.3, K6.14
unnamed: J7.2, K7.12
unnamed: J7.3, K7.14
unnamed: J8.2, K8.12
unnamed: J8.3, K8.14
unnamed: F1.1, J10.1
unnamed: J11.2, R19.1
unnamed: J12.2, R20.1
unnamed: Q1.2 (B), R9.2
unnamed: Q2.2 (B), R10.2
unnamed: Q3.2 (B), R11.2
unnamed: Q4.2 (B), R12.2
unnamed: Q5.2 (B), R13.2
unnamed: Q6.2 (B), R14.2
unnamed: Q7.2 (B), R15.2
unnamed: Q8.2 (B), R16.2
unnamed: R1.1, U1.1
unnamed: R2.1, U2.1
unnamed: R3.1, U5.1
unnamed: R4.1, U6.1
unnamed: R5.1, U7.1
unnamed: R6.1, U8.1
unnamed: R7.1, U9.1
unnamed: R8.1, U10.1
unnamed: R9.1, U1.3
unnamed: R10.1, U2.3
unnamed: R11.1, U5.3
unnamed: R12.1, U6.3
unnamed: R13.1, U7.3
unnamed: R14.1, U8.3
unnamed: R15.1, U9.3
unnamed: R16.1, U10.3
unnamed: R31.2, SW1.2 (B), U3.5 (VDET_1/GPIO34/ADC1_CH6)
unnamed: R32.2, SW2.2 (B), U3.6 (VDET_2/GPIO35/ADC1_CH7)
unnamed: R20.2, R22.1, U3.4 (SENSOR_VN/GPIO39/ADC1_CH3)
unnamed: R19.2, R21.1, U3.3 (SENSOR_VP/GPIO36/ADC1_CH0)

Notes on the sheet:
* POWER SUPPLY +5VDC 5W => ESP32 * POWER SUPPLY +24VDC 10 W => RELAYS
* 8 RELAYS FOR VALVES * POWER DETAIL : CMD => +3V3 / RELAYS => +24VDC / VALVES => 24VAC
* POWER SUPPLY 24VAC 20VA => VALVES

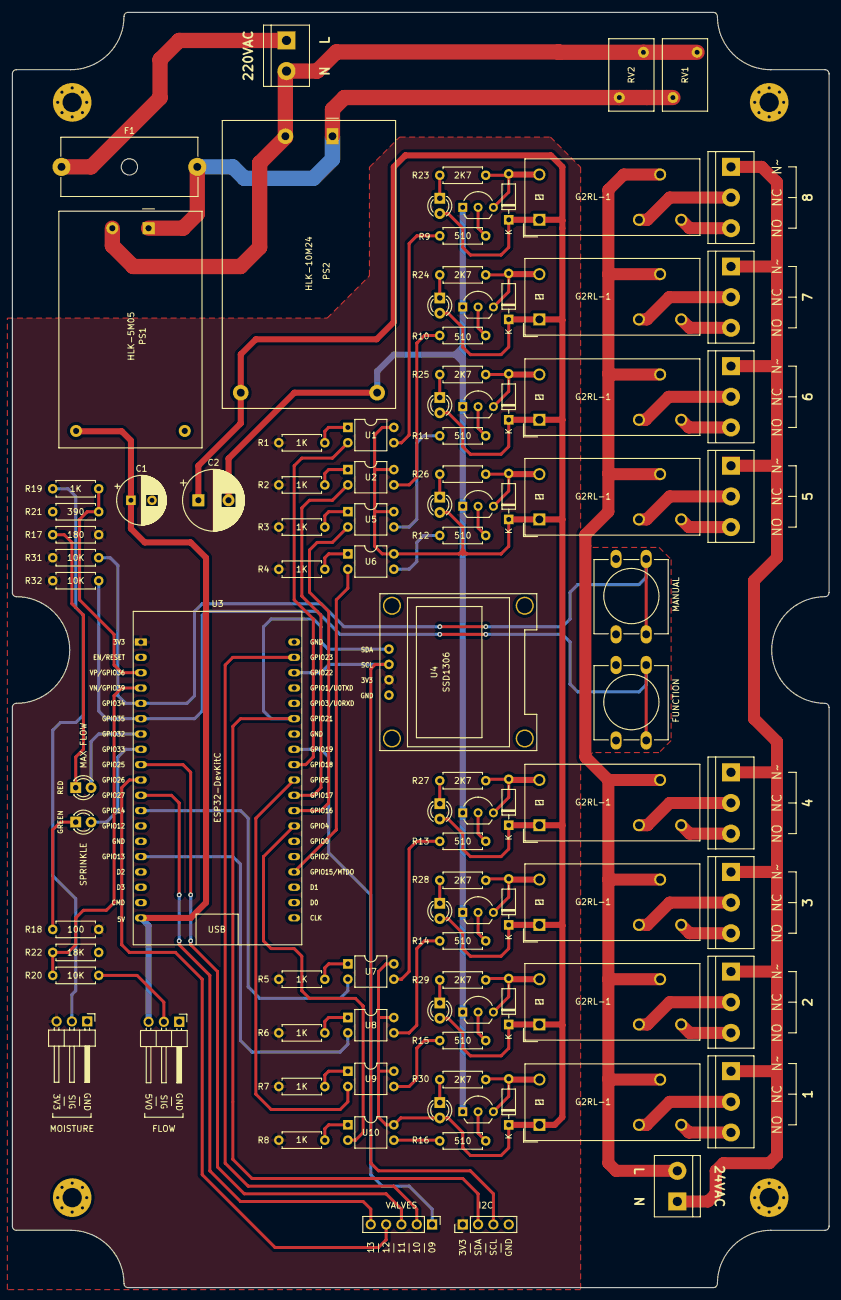
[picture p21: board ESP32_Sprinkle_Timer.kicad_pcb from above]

Board: 2 copper layers, 135.3 x 211.3 mm, 99 parts (0 on the bottom side), 91 nets.

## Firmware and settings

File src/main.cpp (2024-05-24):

#include <Arduino.h>
#include <SPIFFS.h>
#include <AsyncTCP.h>
#include <ESPAsyncWebServer.h>

#include "connect.h"
#include "config.h"
#include "schedule.h"
#include "html.h"
#include "sensors.h"
#include "led.h"
#include "oled.h"
#include "hmi.h"
#include "manager.h"

Config config(CONFIG_FILE);
Schedule schedule(SCHEDULE_FILE);

AsyncWebServer server(80);
Hmi hmi;
bool sntp_sync;

void setup()
{
	Serial.begin(115200);

	// Oled
	if (!display.begin()) {
		Serial.println(F("SSD1327 allocation failed"));
		// DEBUG for (;;); // Don't proceed, loop forever
	}

	// Preferences manager -> Variable for seasonal adjustment
	prefs.begin("sprinkler");

	// Hmi
	hmi.begin();

	// Read config.ini file SPIFFS
	if (!SPIFFS.begin()) {
		Serial.println("SPIFFS.begin() failed");
	}

	// Read config file
	if (config.read() != true) {
		Serial.println("configuration failed");
		// while (1) sleep(1);
	}
	// DEBUG config.print();

	// Schedule file
	if (schedule.read() != true) {
		Serial.println("schedule configuration failed");
		// while (1) sleep(1);
	}
	// DEBUG schedule.print();

	// Reset all relays
	// DEBUG Serial.println("RESET all relays");
	Relay *relay = Relay::getFirst();
	while (relay != 0) {
		if (relay->isPresent()) {
			relay->off();
		}
			relay = Relay::getNext();
	}

	// Close main valve and wait for state -> VALVE_IS_CLOSED
	Valve::getMainValve()->close();
	while (Valve::getMainValve()->getState() != VALVE_IS_CLOSED) {}

	// Set WiFi parameters and SNTP server time
	ConfigConnect::initWiFi(config.getSsid(), config.getPassword());
	ConfigConnect::initSNTP();

	// Websocket
	initWebSocket();

  	// Main HTML page
	server.on("/", handleRoot);

	// Edit Schedules page
	server.on("/edit", handleEdit);
	server.on("/edit_submit", handleEditSubmit);
	server.on("/add", handleAdd);
	server.on("/remove", handleRemove);
	server.on("/weather", handleWeather);

  	// Files CSS
	server.on("/w3.css", HTTP_GET, [](AsyncWebServerRequest *request) {
		request->send(SPIFFS, "/w3.css", "text/css");
	});

	server.on("/w3-theme.css", HTTP_GET, [](AsyncWebServerRequest *request) {
		request->send(SPIFFS, "/w3-theme.css", "text/css");
	});
  
	server.on("/style.css", HTTP_GET, [](AsyncWebServerRequest *request) {
		request->send(SPIFFS, "/style.css", "text/css");
	});

	server.on("/edit.css", HTTP_GET, [](AsyncWebServerRequest *request) {
		request->send(SPIFFS, "/edit.css", "text/css");
	});

	// Files JS
	server.on("/fontawesome.min.js", HTTP_GET, [](AsyncWebServerRequest *request) {
    	request->send(SPIFFS, "/fontawesome.min.js", "text/javascript");
	});

  	server.on("/scripts.js", HTTP_GET, [](AsyncWebServerRequest *request) {
    	request->send(SPIFFS, "/scripts.js", "text/javascript");
	});

  	server.on("/edit.js", HTTP_GET, [](AsyncWebServerRequest *request) {
    	request->send(SPIFFS, "/edit.js", "text/javascript");
	});

	// Start AsyncWebServer
	server.begin();

	// Init flow sensor
	flowInit();

	// Init LED
	ledInit();

	// Clear message
	display.clearMessage();
}

void loop()
{
	cleanUpClient();

	static time_t lastSec, lastFlow;
	time_t timestamp = time(NULL);
	float flow;

	if (sntp_get_sync_status() == SNTP_SYNC_STATUS_COMPLETED) {
    	sntp_sync = true;
  	}
	
	if (sntp_sync) {
		if (timestamp > 10) {

			if (timestamp - lastFlow >= 1) {
				lastFlow = timestamp;
				flow = getFlow();
				display.displayFlow(flow); 			// Display to SSD1327
				
				if (flow > Config::getConfig()->getMaxFlow()) {
					// DEBUG Serial.printf("flow is too high\n");
					Watering::stopAllAutoWatering();
					Way::stopAllManualWatering();
					ledWrite(OVERFLOW_LED, ON);
				} else {
					ledWrite(OVERFLOW_LED, OFF);
				}
			}

			if (timestamp - lastSec >= 10) { // 60
				int moisture;
				getSoilMoisture(&moisture);
				if (!hmi.isBusy()) {
					hmi.displayNextWatering();		// Display to SSD1327
				}
				display.displayMoisture(moisture); 	// Display to SSD1327
				display.displayTimeDate();			// Display to SSD1327
				display.displayIP();				// Display to SSD1327
				lastSec = timestamp;
				Watering::run(timestamp);
			}
		}
		hmi.run();
	}
}

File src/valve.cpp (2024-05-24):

#include "valve.h"
#include "led.h"
#include "oled.h"

Ticker timer;
Valve Valve::m_mainValve;

/********** Constructor ***********/
Valve::Valve(void) : m_state(VALVE_UNKNOWN)
{
}


/********** Timer callback ***********/
void changeState(Valve *v)
{
    if (v->getState() == VALVE_IS_OPENING) {
        v->isOpen();
    } else if (v->getState() == VALVE_IS_CLOSING) {
        v->isClosed();
    }
    display.clearMessage();
    timer.detach();
}


/********** Create main valve ***********/
bool Valve::create(const char *def)
{
    char tmp[MAX_DEF];
    const char *p;
    char *s;

    Serial.printf("main valve::create %s\n", def);
    strncpy(tmp, def, MAX_DEF);
    p = strtok_r(tmp, ", ", &s);
    if (p == NULL) {
        Serial.printf("%s: bad value\n", def);
        return false;
    }
    m_mainValve.m_openRelay = Relay::getByName(p);

    if (m_mainValve.m_openRelay == 0) {
        Serial.printf("%s: bad value for open relay\n", def);
        return false;
    }
    p = strtok_r(NULL, ", ", &s);
    if (p == NULL) {
        return true;
    }
    m_mainValve.m_closeRelay = Relay::getByName(p);
  
    if (m_mainValve.m_closeRelay == 0) {
        Serial.printf("%s: bad value for close relay\n", def);
        return false;
    }
    return true;
}


/********** Get main valve ***********/
Valve *Valve::getMainValve(void)  {
    return &m_mainValve;
}


/********** Open main valve ***********/
void Valve::open(void)
{
    if (m_state == VALVE_IS_CLOSED) {
        display.displayMessage("Valve is opening");
        if (m_closeRelay) {
            // it's a motorized valve (2 relays)
            m_openRelay->on();
            m_state = VALVE_IS_OPENING;
            timer.attach(OPEN_TIME, changeState, this);
        } else {
            // it's a normal valve
            m_openRelay->on();
            m_state = VALVE_IS_OPEN;
        }
    }
}


/********** Close main valve ***********/
void Valve::close(void)
{
    if (m_state == VALVE_IS_OPEN || m_state == VALVE_UNKNOWN) {
        display.displayMessage("Valve is closing");
        if (m_closeRelay) {
            // it's a motorized valve (2 relays)
            m_closeRelay->on();
            m_state = VALVE_IS_CLOSING;
            timer.attach(OPEN_TIME, changeState, this);
        } else {
            // it's a normal valve
            m_openRelay->off();
            m_state = VALVE_IS_CLOSED;
        }
    }
}


/********** Motorized valve is open ***********/
void Valve::isOpen(void)
{
    Serial.printf(">>>> VALVE is OPEN\n");
    ledWrite(WATERING_LED, ON);
    m_state = VALVE_IS_OPEN;
    m_openRelay->off();
}


/********** Motorized valve is closed ***********/
void Valve::isClosed(void)
{
    Serial.printf(">>>> VALVE is CLOSED\n");
    ledWrite(WATERING_LED, OFF);
    m_state = VALVE_IS_CLOSED;
    m_closeRelay->off();
}


/********** Print main valve **********/ 
// void Valve::print(void) -> valeurs erronées
// {
//     Serial.printf("main valve: %s %s\n", m_openRelay ? m_openRelay->getName() : "NONE", m_closeRelay ? m_closeRelay->getName() : "NONE");
// }

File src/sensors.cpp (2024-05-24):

#include <Arduino.h>

#include "config.h"
#include "sensors.h"

// Humidity sensor
int getSoilMoisture(int *value)
{
    uint8_t sensor = Config::getConfig()->getMoistureSensor();
    if (sensor != 0) {
        uint8_t maxMoisture = Config::getConfig()->getMaxMoisture();
        unsigned percent = 100 - maxMoisture;       // Reverse percentage
        unsigned intervals = (HUMIDITY_AIR - HUMIDITY_WATER) / (100 / percent);
        unsigned limit = HUMIDITY_WATER + intervals;
        analogSetPinAttenuation(sensor, ADC_0db);   // See if it's necessary
        unsigned soilMoistureValue = analogRead(sensor);
        soilMoistureValue = soilMoistureValue < HUMIDITY_WATER ? HUMIDITY_WATER : soilMoistureValue;
        soilMoistureValue = soilMoistureValue > HUMIDITY_AIR ? HUMIDITY_AIR : soilMoistureValue;
        unsigned maxDiff = HUMIDITY_AIR - HUMIDITY_WATER;
        unsigned tmp = HUMIDITY_AIR - soilMoistureValue;
        unsigned diff = maxDiff - tmp;
        *value = 100 - (diff * 100 / maxDiff);
            
        if (soilMoistureValue < (limit)) {
            // DEBUG Serial.printf("Humidity: %d (limit %d), WET\n", soilMoistureValue, limit);
            return HUMIDITY_WET;
        }
        else {
            // DEBUG Serial.printf("Humidity: %d (limit %d), DRY\n", soilMoistureValue, limit);
            return HUMIDITY_DRY;
        }
    }
    Serial.printf("Humidity: no sensor, DRY\n");
    *value = 50;
    return HUMIDITY_DRY;
}


// Flow sensor
#define SENSOR_INTERRUPT digitalPinToInterrupt(FLOW_SENSOR)

float calibrationFactor = 1.08;

static volatile byte pulseCount;
static unsigned long total;

unsigned long oldTime;

void IRAM_ATTR pulseCounter()
{
    pulseCount++;
}

void flowInit(void)
{
    uint8_t sensor = Config::getConfig()->getFlowSensor();
    if (sensor != 0) {
        pinMode(sensor, INPUT_PULLUP);
        attachInterrupt(digitalPinToInterrupt(sensor), pulseCounter, FALLING);
    }
}

float getFlow(void)
{
    float flowRate = 0;
    unsigned int milliLiters;

    if (Config::getConfig()->getFlowSensor() == 0) {
        return 0.0;
    }
    if (millis() - oldTime == 0) {
        return 0;
    }
    noInterrupts();
    flowRate = ((1000.0 / (millis() - oldTime)) * pulseCount) / calibrationFactor;
    oldTime = millis();
    milliLiters = (flowRate / 60) * 1000;
    total += milliLiters;
    pulseCount = 0;
    interrupts();
    // DEBUG Serial.printf("flow: %f\n", flowRate);
    return flowRate;
}
